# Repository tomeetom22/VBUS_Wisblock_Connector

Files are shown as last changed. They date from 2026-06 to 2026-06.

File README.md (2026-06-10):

# VBUS WisBlock Connector KiCad Projects

This repository contains the KiCad PCB project for the VBUS WisBlock SPI breakout board.

## Projects

| Directory | Purpose | Current state |
| --- | --- | --- |
| `SPI_breakout/` | WisBlock SPI breakout for an Adafruit 4682 MicroSD reader, two AlphaSense OPC-N3 particle counters, and two gas/I2C-style terminal ports. | Schematic and routed PCB are present, with local custom symbols, footprints, 3D models, and updated docs. |

## SPI_breakout Overview

`SPI_breakout` is a KiCad 10 project using local project libraries under `SPI_breakout/MyParts.pretty/`.

The board connects the WisBlock 40-pin IO connector to:

- one Adafruit 4682 MicroSD breakout on the shared SPI bus
- two AlphaSense OPC-N3 screw-terminal ports on the shared SPI bus
- two 4-position gas/I2C-style screw terminals
- a separate external 5 V input for OPC-N3 sensor power

The project-level files live in `SPI_breakout/`:

- `SPI_breakout.kicad_pro` - KiCad project file
- `SPI_breakout.kicad_sch` - schematic
- `SPI_breakout.kicad_pcb` - routed PCB
- `fp-lib-table` and `sym-lib-table` - project library tables
- `MyParts.pretty/` - local symbols and footprints
- `1935161.stp`, `1984633.stp`, `1984659.stp`, `4682 Micro SD Breakout.step` - local 3D models
- `PARTS.md` - current BOM and connector pinout summary

## Parts

See [`SPI_breakout/PARTS.md`](SPI_breakout/PARTS.md) for the current parts list, connector pinouts, and assembly notes.

| Qty | Ref | Function | Footprint |
| ---: | --- | --- | --- |
| 1 | `U1` | WisBlock 40-pin IO board connector, TXGA FBB04004-F40S1003K6M | `MyParts:TXGA_FBB04004-F40S1003K6M` |
| 1 | `U2` | Adafruit 4682 MicroSD breakout | `MyParts:Adafruit4682` |
| 1 | `U2 header` | 1x9, 2.54 mm, 90 degree male-to-male pin header set for Adafruit 4682 | fits `MyParts:Adafruit4682` |
| 2 | `J1`, `J2` | OPC-N3 6-position 3.81 mm pluggable PCB headers, Phoenix Contact 1984659 | `MyParts:CONN_1984659_PXC` |
| 1 | `J3` | External OPC 5 V input terminal, Phoenix Contact 1935161 | `MyParts:CONN_1935161_PXC` |
| 2 | `GAS1`, `GAS2` | 4-position 3.81 mm pluggable PCB headers, Phoenix Contact 1984633 | `MyParts:CONN_1984633_PXC` |

## Main Connections

| Function | WisBlock IO pin | Net |
| --- | ---: | --- |
| MicroSD chip select | 25 | `SD_CS` |
| SPI clock | 26 | `SPI_CLK` |
| SPI MISO | 27 | `SPI_MISO` |
| SPI MOSI | 28 | `SPI_MOSI` |
| OPC-N3 A chip select | 29 | `OPC1_CS` |
| OPC-N3 B chip select | 31 | `OPC2_CS` |
| MicroSD 3.3 V | 18 | `Net-(U2-3v3)` |
| GAS1 3.3 V / SDA / SCL | 17 / 19 / 20 | `Net-(GAS1-VCC)` / `Net-(GAS1-SDA)` / `Net-(GAS1-SCL)` |
| GAS2 3.3 V / SDA / SCL | 5 / 35 / 36 | `Net-(GAS2-VCC)` / `Net-(GAS2-SDA)` / `Net-(GAS2-SCL)` |
| Ground | 40 plus shared returns | `GND` |

## OPC and Power Notes

OPC-N3 sensor 5 V is supplied externally through `J3`; it is not tied to the WisBlock 3.3 V rail. `J3` pin 1 feeds `OPC_5V_EXT` for `J1`/`J2` pin 2, and `J3` pin 2 ties the OPC supply return to WisBlock ground.

The SPI nets are 3.3 V logic. The schematic notes do not include a level shifter, so the WisBlock IO connector, MicroSD breakout, and OPC SPI adapter are expected to be 3.3 V logic compatible before applying external 5 V OPC power.

OPC terminal pin order from the schematic:

| Terminal pin | OPC wire | Signal |
| ---: | --- | --- |
| 1 | Black | `GND` |
| 2 | Red | `OPC_5V_EXT` |
| 3 | Green | SS / chip select |
| 4 | Blue | SDI / `SPI_MOSI` |
| 5 | White | SDO / `SPI_MISO` |
| 6 | Yellow | SCK / `SPI_CLK` |

## Opening the Project

1. Open `SPI_breakout/SPI_breakout.kicad_pro` in KiCad.
2. For `SPI_breakout`, keep the project-relative library paths intact:
   - `SPI_breakout/fp-lib-table`
   - `SPI_breakout/sym-lib-table`
   - `SPI_breakout/MyParts.pretty/`
3. After schematic changes, run **Update PCB from Schematic** in KiCad before adjusting placement or routing.
4. Press `B` in PCB Editor to refill copper zones if the ground pour only shows as a dashed outline.

## Before Fabrication

- Verify physical fit against the RAK base board and any enclosure.
- Confirm terminal access direction and wire service clearance.
- Run KiCad GUI ERC/DRC.
- Refill zones and inspect `GND` pour clearances.
- Generate fresh Gerbers and drill files from the final board.

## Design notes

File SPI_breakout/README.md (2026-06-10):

# SPI_breakout

KiCad project for a WisBlock IO SPI breakout board. The board brings the WisBlock 40-pin IO connector out to:

- two AlphaSense OPC-N3 screw-terminal ports on the shared SPI bus
- one Adafruit 4682 MicroSD breakout footprint on the same SPI bus
- two 4-position gas/I2C-style screw terminals
- a separate 5 V input terminal for OPC-N3 sensor power

## Project Files

- `SPI_breakout.kicad_pro` - KiCad project file
- `SPI_breakout.kicad_sch` - schematic
- `SPI_breakout.kicad_pcb` - routed PCB
- `MyParts.pretty/` - local symbols and footprints
- `1935161.stp`, `1984633.stp`, `1984659.stp`, `4682 Micro SD Breakout.step` - local 3D models
- `SPI_breakout.zip` - existing board output archive
- `PARTS.md` - current parts and connector pinout summary

## Electrical Notes

OPC-N3 sensor 5 V is supplied externally through `J3`; it is not tied to the WisBlock 3.3 V rail. `J3` pin 1 feeds `OPC_5V_EXT` for `J1`/`J2` pin 2, and `J3` pin 2 ties the OPC supply return to WisBlock ground.

The SPI nets are 3.3 V logic. The schematic notes do not include a level shifter, so the WisBlock IO connector, MicroSD breakout, and OPC SPI adapter are expected to be 3.3 V logic compatible before applying external 5 V OPC power.

## Main Connections

| Function | WisBlock IO pin | Net |
| --- | ---: | --- |
| MicroSD chip select | 25 | `SD_CS` |
| SPI clock | 26 | `SPI_CLK` |
| SPI MISO | 27 | `SPI_MISO` |
| SPI MOSI | 28 | `SPI_MOSI` |
| OPC-N3 A chip select | 29 | `OPC1_CS` |
| OPC-N3 B chip select | 31 | `OPC2_CS` |
| MicroSD 3.3 V | 18 | `Net-(U2-3v3)` |
| Ground | 40 | `GND` |

See `PARTS.md` for connector part numbers, quantities, and pinouts.

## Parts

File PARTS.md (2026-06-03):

# SPI_breakout Parts List

This is the working parts list for `SPI_breakout/`.

| Qty | Ref | Part | Notes |
| ---: | --- | --- | --- |
| 1 | `U1` | TXGA `FBB04004-F40S1003K6M` or matching WisBlock 40-pin board-to-board connector | Footprint: `MyParts:TXGA_FBB04004-F40S1003K6M`. Verify exact mating height against the RAK base board. |
| 1 | `U2` | Adafruit 4682 microSD SPI/SDIO breakout | Powered from WisBlock 3.3 V. |
| 2 | `J1`, `J2` | 6-position 3.81 mm pluggable terminal header | Footprint uses Phoenix MC style: `PhoenixContact_MC_1,5_6-G-3.81_1x06_P3.81mm_Horizontal`. Intended for Digi-Key `TJ0631030000G`-style 6-position plug plus compatible PCB header. |
| 1 | `J3` | 2-position 3.81 mm pluggable terminal header | External 5 V input for OPC power. Use compatible plug/header pair. |
| 2 | External | AlphaSense OPC-N3 | Connected through `J1` and `J2`; not mounted directly to PCB. |
| 1 | External | Regulated 5 V supply for OPC-N3 sensors | Connects to `J3`; return ground is common with WisBlock ground. |
| 1 | External | RAK WisBlock base / IO host | Provides 3.3 V logic, SPI bus, and GPIO chip-select lines. |

## Terminal Pinout

`J1` and `J2` use the same pin order:

| Pin | Wire color | Signal |
| ---: | --- | --- |
| 1 | Black | GND |
| 2 | Red | External 5 V |
| 3 | Green | SS / chip select |
| 4 | Blue | SDI / MOSI |
| 5 | White | SDO / MISO |
| 6 | Yellow | SCK |

`J3` pinout:

| Pin | Signal |
| ---: | --- |
| 1 | External 5 V |
| 2 | GND |

## Procurement Notes

- `TJ0631030000G` is a 6-position 3.81 mm pluggable terminal plug. Pair it with
  a compatible 3.81 mm PCB header matching the selected footprint and desired
  wire-entry direction.
- The OPC-N3 is powered from 5 V, but the board assumes SPI logic is safe for
  WisBlock 3.3 V pins. Confirm the OPC wiring/adapter does not return 5 V logic
  before fabrication.

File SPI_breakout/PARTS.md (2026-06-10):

# SPI_breakout Parts

Parts summary generated from the current KiCad schematic and PCB files.

## BOM

| Qty | Ref | Part / description | Footprint | Notes |
| ---: | --- | --- | --- | --- |
| 1 | U1 | TXGA FBB04004-F40S1003K6M 40-pin WisBlock IO board connector | `MyParts:TXGA_FBB04004-F40S1003K6M` | SMD connector on bottom side. |
| 1 | U2 | Adafruit 4682 MicroSD breakout | `MyParts:Adafruit4682` | Through-hole 1x9 header footprint for the breakout. |
| 1 | U2 header | 1x9, 2.54 mm, 90 degree male-to-male pin header set | fits `MyParts:Adafruit4682` | Added for mounting the Adafruit 4682 at right angle. Breakaway right-angle male header is OK if cut to 9 pins. |
| 2 | J1, J2 | Phoenix Contact 1984659, 6-position 3.81 mm pluggable PCB header | `MyParts:CONN_1984659_PXC` | OPC-N3 A/B connectors. Matching plug noted on schematic: TJ0631030000G or equivalent. |
| 1 | J3 | Phoenix Contact 1935161, 2-position external OPC 5 V input terminal | `MyParts:CONN_1935161_PXC` | Feeds only the OPC 5 V rail plus common return. |
| 2 | GAS1, GAS2 | Phoenix Contact 1984633, 4-position 3.81 mm pluggable PCB header | `MyParts:CONN_1984633_PXC` | Gas/I2C-style terminal blocks. |
| 3 | H1, H3, H4 | 1.5 mm mounting holes | `RAK_IO_FIX_SMALL` | Board mounting features. |
| 2 | H2, H5 | 2.8 mm mounting holes | `RAK_IO_FIX_LARGE` | Board mounting features. |

## Connector Pinouts

### J1 - OPC-N3 A

| Pin | Signal | Wire color from schematic note |
| ---: | --- | --- |
| 1 | `GND` | black |
| 2 | `OPC_5V_EXT` | red |
| 3 | `OPC1_CS` / SS | green |
| 4 | `SPI_MOSI` / SDI | blue |
| 5 | `SPI_MISO` / SDO | white |
| 6 | `SPI_CLK` / SCK | yellow |

### J2 - OPC-N3 B

| Pin | Signal | Wire color from schematic note |
| ---: | --- | --- |
| 1 | `GND` | black |
| 2 | `OPC_5V_EXT` | red |
| 3 | `OPC2_CS` / SS | green |
| 4 | `SPI_MOSI` / SDI | blue |
| 5 | `SPI_MISO` / SDO | white |
| 6 | `SPI_CLK` / SCK | yellow |

### J3 - External OPC 5 V Input

| Pin | Signal |
| ---: | --- |
| 1 | `OPC_5V_EXT` |
| 2 | `GND` |

### U2 - Adafruit 4682 MicroSD Breakout

| Pin | Signal |
| ---: | --- |
| 1 | `3v3` from WisBlock IO pin 18 |
| 2 | `GND` |
| 3 | `SPI_CLK` |
| 4 | `SPI_MISO` / D0/SO |
| 5 | `SPI_MOSI` / D1/CMD |
| 6 | `SD_CS` |
| 7 | DAT1, unconnected |
| 8 | DAT2, unconnected |
| 9 | DET, unconnected |

### GAS1

| Pin | Signal | WisBlock IO pin |
| ---: | --- | ---: |
| 1 | `VCC` / 3.3 V | 17 |
| 2 | `GND` | common ground |
| 3 | `SCL1` | 20 |
| 4 | `SDA1` | 19 |

### GAS2

| Pin | Signal | WisBlock IO pin |
| ---: | --- | ---: |
| 1 | `VCC` / 3.3 V | 5 |
| 2 | `GND` | common ground |
| 3 | `SCL2` | 36 |
| 4 | `SDA2` | 35 |

## Assembly Notes

- Supply OPC 5 V through `J3`; do not expect the WisBlock 3.3 V rail to power OPC-N3 sensors.
- Verify the OPC SPI interface is 3.3 V logic compatible before applying external 5 V power.
- Use a 1x9 right-angle male header for the Adafruit 4682 so the breakout mates with the `U2` through-hole footprint.

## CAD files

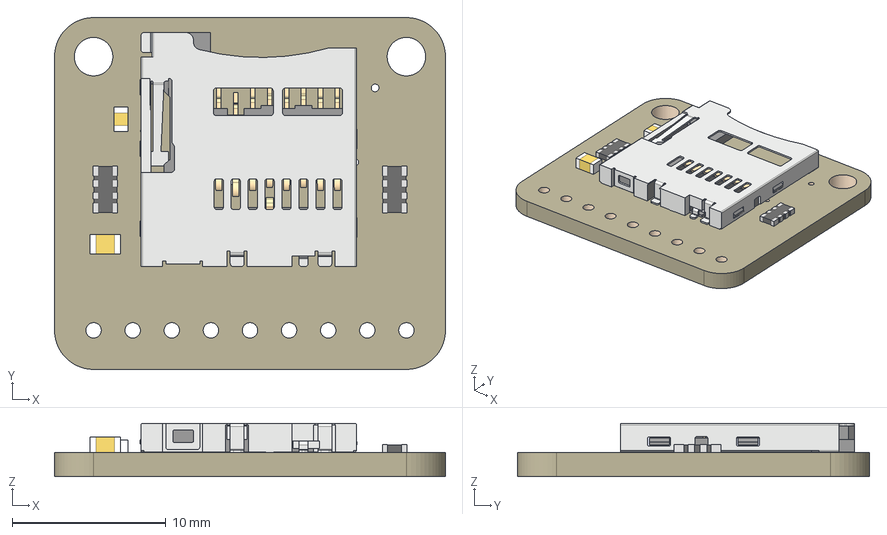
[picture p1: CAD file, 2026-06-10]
SPI_breakout/4682 Micro SD Breakout.step
25.4 x 22.9 x 3.45 mm
Board
microSD
10uF
0.1uF
47K x 2

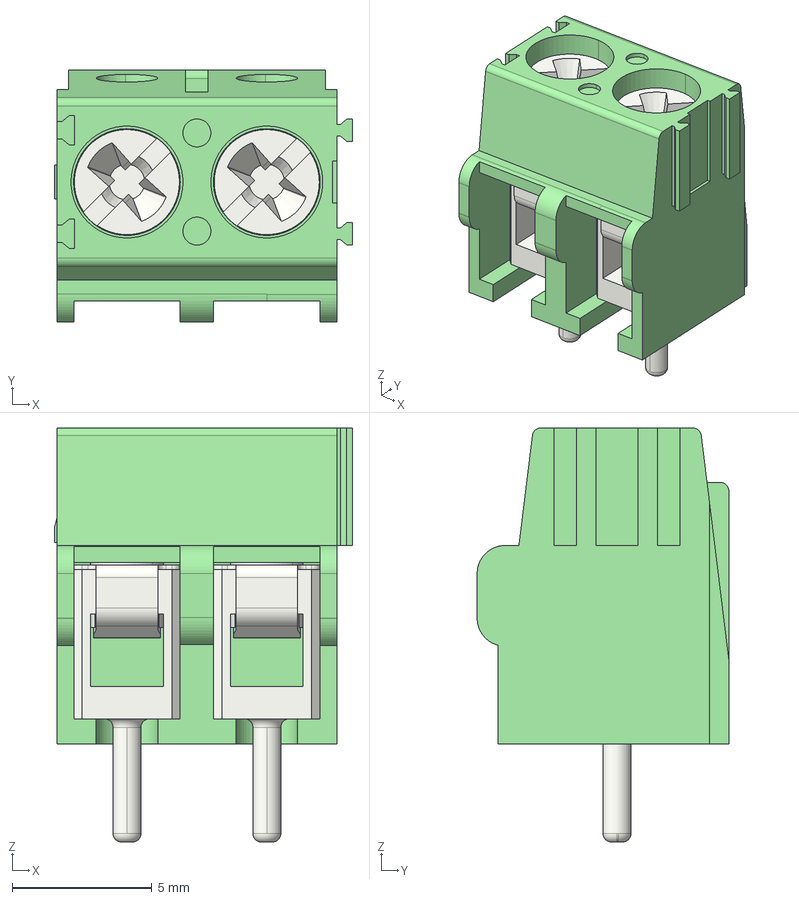
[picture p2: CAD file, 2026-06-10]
SPI_breakout/1935161.stp
10.7 x 9.00 x 14.8 mm

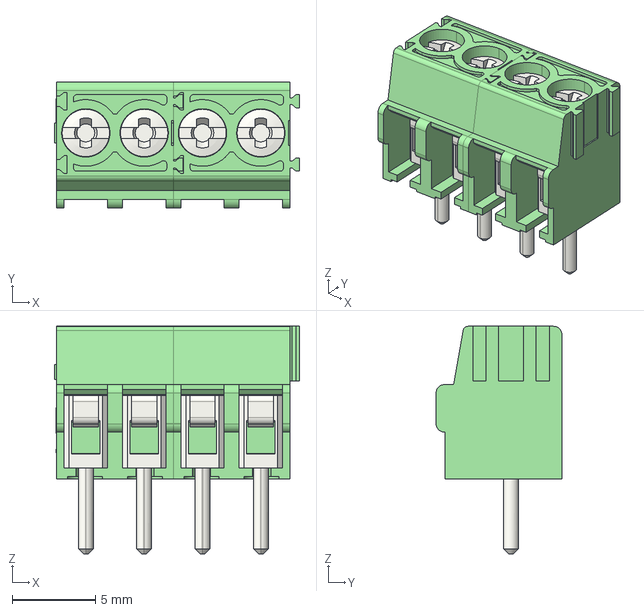
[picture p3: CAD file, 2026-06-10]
SPI_breakout/1984633.stp
14.7 x 7.55 x 13.7 mm

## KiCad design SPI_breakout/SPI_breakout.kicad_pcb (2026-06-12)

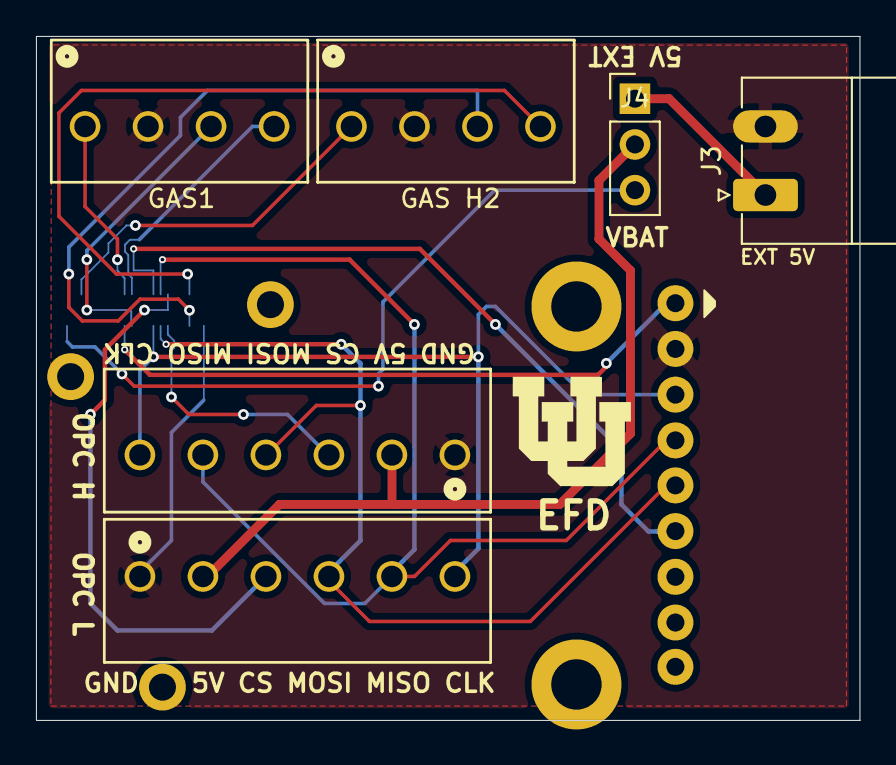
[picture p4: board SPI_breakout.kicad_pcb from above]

Board: 2 copper layers, 45.8 x 38.0 mm, 13 parts (1 on the bottom side), 17 nets.

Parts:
GAS1, GAS2: Screw_Terminal_01x04; CONN_1984633_PXC
H1, H3, H4: Mount 1.5mm; RAK_IO_FIX_SMALL
H2, H5: Mount 2.8mm; RAK_IO_FIX_LARGE
J1: OPC-N3 A; CONN_1984659_PXC
J2: OPC-N3 B; CONN_1984659_PXC
J3: External OPC 5V Input; PhoenixContact_MC_1,5_2-G-3.81_1x02_P3.81mm_Horizontal
J4: Jumper; PinHeader_1x03_P2.54mm_Vertical
U1: TXGA_FBB04004-F40S1003K6M
U2: Adafruit4682

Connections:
/EXT_5V: J3.1 (5V_EXT), J4.1 (EXT_5V)
/OPC1_CS: J1.3 (SS), U1.29 (IO1)
/OPC2_CS: J2.3 (SS), U1.30 (IO2)
/OPC_5V: J1.2 (5V_EXT), J2.2 (5V_EXT), J4.2 (OPC_5V)
/SD_CS: U1.25 (SPI_CS), U2.6 (CS)
/SPI_CLK: J1.6 (SCK), J2.6 (SCK), U1.26 (SPI_CLK), U2.3 (CLK)
/SPI_MISO: J1.5 (SDO_MISO), J2.5 (SDO_MISO), U1.27 (SPI_MISO), U2.4 (D0_SO)
/SPI_MOSI: J1.4 (SDI_MOSI), J2.4 (SDI_MOSI), U1.28 (SPI_MOSI), U2.5 (D1_CMD)
GND: GAS1.2 (GND), GAS2.2 (GND), J1.1 (GND), J2.1 (GND), J3.2 (GND), U1.40 (GND), U2.2 (GND)
unnamed: GAS1.3 (SCL), U1.20 (SCL1)
unnamed: GAS1.4 (SDA), U1.19 (SDA1)
unnamed: GAS1.1 (VCC), U1.17 (3v3)
unnamed: GAS2.3 (SCL), U1.36 (SCL2)
unnamed: GAS2.4 (SDA), U1.35 (SDA2)
unnamed: GAS2.1 (VCC), U1.5 (3v3)
unnamed: J4.3 (VBAT), U1.2 (VBAT)
unnamed: U1.18 (3v3), U2.1 (3v3)

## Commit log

2026-06-03 AI assisted edits on board
    [SPI_breakout.kicad_pcb, SPI_breakout.kicad_sch]
2026-06-10 Reworking routing
    [SPI_breakout.kicad_pcb, SPI_breakout.kicad_sch]
2026-06-10 Rework into smaller footprint and add 3D models
    [1935161.stp, 1984633.stp, 4682 Micro SD Breakout.step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]
2026-06-10 Stop tracking reference folder /SensorBoard_v1.5
    [SensorBoard_v1.5-B_Cu.gbr, SensorBoard_v1.5-B_Mask.gbr, SensorBoard_v1.5-B_Paste.gbr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]
2026-06-10 Cleaning up routes
    [SPI_breakout.kicad_pcb, SPI_breakout.kicad_sch]
2026-06-11 Added power switching and bigger pad for SD mount
    [SPI_breakout.kicad_pcb, SPI_breakout.kicad_sch]
2026-06-11 Change IO pin to 2 to avoid GPS conflict
    [SPI_breakout.kicad_pcb, SPI_breakout.kicad_sch]
2026-06-12 Final checks
    [SPI_breakout.kicad_pcb, SPI_breakout.kicad_sch]
